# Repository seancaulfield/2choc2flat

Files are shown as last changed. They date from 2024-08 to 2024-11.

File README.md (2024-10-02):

# 2 Choc 2 Flat v1.5 and v2.1

2 Choc 2 Flat PCB
Low profile 60% PCB designed for Choc V2 switches in hot swap sockets. Based on the Plain60-C design. Four versions are provided:

* ISO(ish) without lighting
* ANSI without lighting
* ISO(ish) with RGB per-key and underglow
* ANSI with RGB per-key and underglow (TODO)

## Features

- Compatible with QMK Firmware
- Compatible with cases supporting the GH60 layout
- LED for capslock for non-RGB versions
- Minimal layout support due to hot swap sockets
- ANSI has 64 keys; ISO(ish) has 65 (split backspace)
- Both use 2U left shift keys to squeeze in the arrow cluster

## Notes/Cautions

ISO(ish) boards will need to get a custom plate cut, as there are no
commercially available ones I've found. Files for this are included in the
`plate` directory within the project directory for each ISO version.

The layout used is the 2U left shift 60% layout, which allows the arrow cluster
to be included. Check your keycap compatibility before using.

## Bill of materials (BOM)

For all versions:

* 64-65 Kailh Choc hot swap sockets (depending on variant)
* 64-65 SOD-323 diodes
* Gateron low-profile stabilizers (1 6.25U, 2-3 2U)
* Plate compatible with Gateron low-profile stabilizers
  * any Cherry plate mount stabilizer compatible should do
  * e.g. [this one at Adafruit](https://www.adafruit.com/product/5133)
  * DXF/SVG/EPS files for ISOish plates are in the project directories for them
* Waveshare RP2040 Tiny, which has the USB port attached via FFC
  * [Amazon](https://www.amazon.com/dp/B0C4FC84V9)
  * [Aliexpress](https://www.aliexpress.us/item/3256806201372671.html)

For non-RGB versions, you will also need:

* 2 1206 reverse mount LEDs (for capslock)
* 2 0603 ~470ohm resistors (for capslock LEDs)

For RGB versions, you will also need:

* 64-65 SK6812-E reverse mount NeoPixel RGB LEDs
* 16 NeoPixel Nano 2020 RGB LEDs
* 1 SN74LVC2G125DCT SSOP-8 buffer chip
* 0603 1u(ish) X5R capacitor

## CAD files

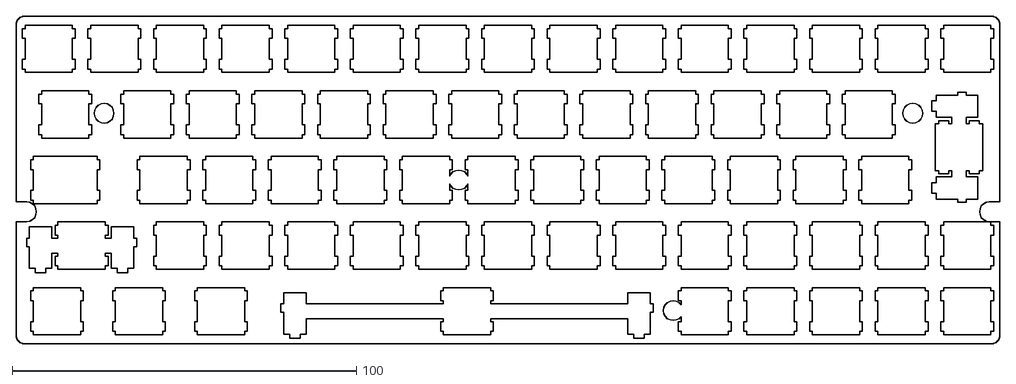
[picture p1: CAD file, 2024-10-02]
2choc2flat-extmcu-iso-solder/plate/s64-2u-lshift-iso-plate-2.dxf
285.6 x 95.2

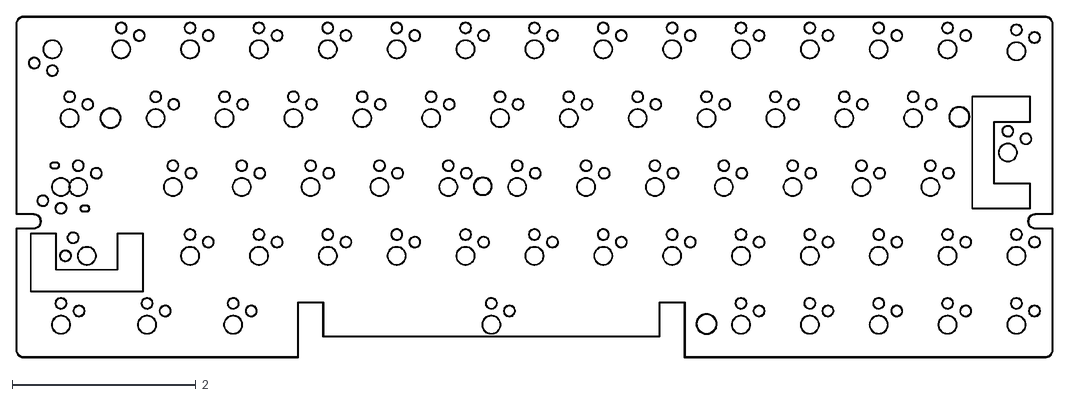
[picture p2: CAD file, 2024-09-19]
2choc2flat-extmcu-iso-solder/foam/2choc2flat-extmcu-iso-User_Eco2_v2.3.dxf
11.3 x 3.72

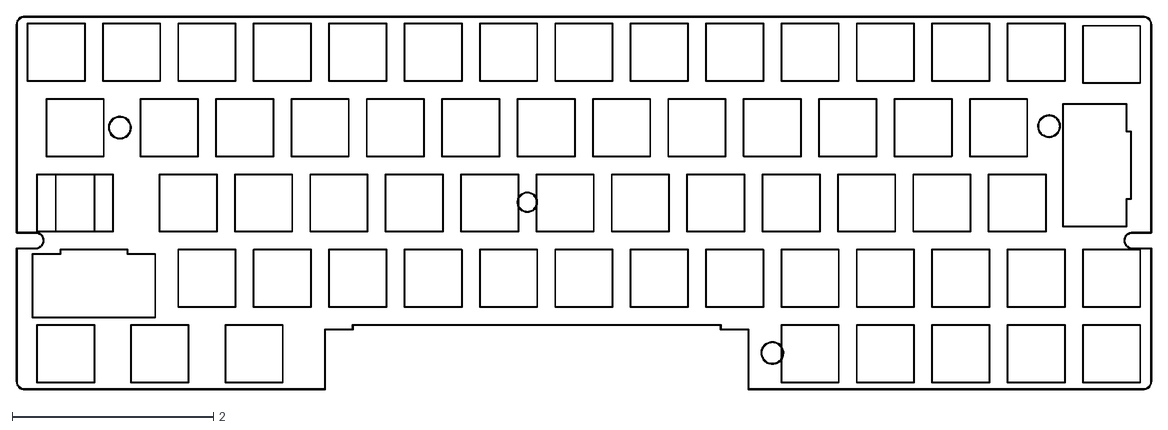
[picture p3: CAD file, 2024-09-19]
2choc2flat-extmcu-iso-solder/foam/2choc2flat-extmcu-iso-User_Eco1_v2.3.dxf
11.3 x 3.72

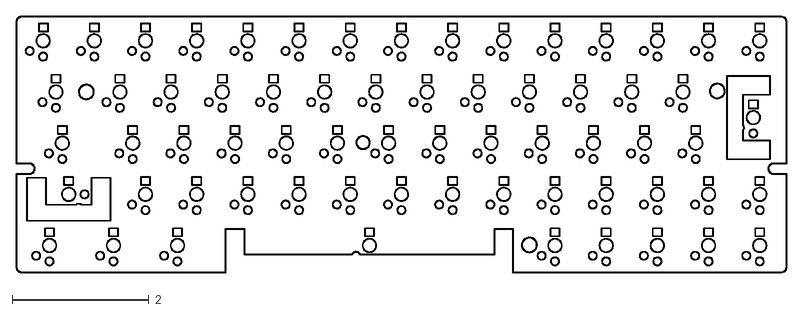
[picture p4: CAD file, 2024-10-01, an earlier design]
2choc2flat-extmcu-iso-solder/foam/2choc2flat-extmcu-iso-User_Eco2_v2.1.dxf
11.3 x 3.76

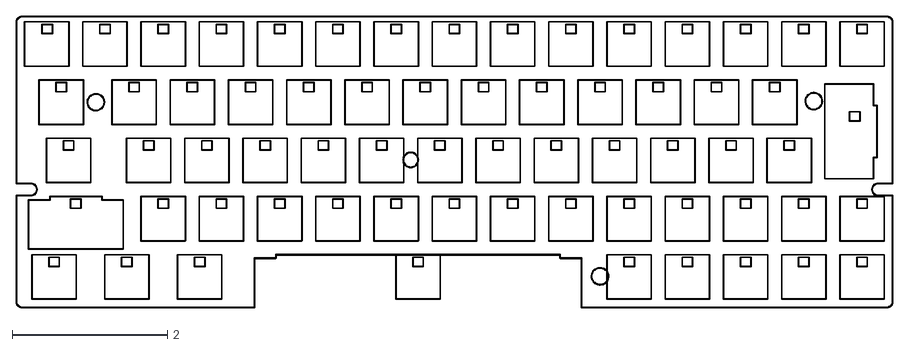
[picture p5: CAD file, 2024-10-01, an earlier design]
2choc2flat-extmcu-iso-solder/foam/2choc2flat-extmcu-iso-User_Eco1_v2.1.dxf
11.3 x 3.76

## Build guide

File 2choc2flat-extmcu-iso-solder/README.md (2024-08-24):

# Plain60-C rev2.2

Plain60-C PCB
This universal 60% PCB is designed to support as little layouts as possible without limiting usability for most users. The reason I did this is because other PCBs made for this form factor usually have so many supported layouts that it could almost qualify as swiss cheese.

It also features a fuse and an ESD protection chip to protect the MCU and other parts of the PCB.

## Features
- Compatible with QMK Firmware and VIA Configurator (if you flash a VIA compatible .hex file)
- Compatible with most universal 60% cases and HHKB/WKL Tofu by KBDfans
- USB type-C
- Optional JST header for connection with daughterboard
- Footprint for optional speaker (AST1109MLTRQ)
- ESD protection and fuse
- No LEDs and no underglow
- Minimal layout support
- ISP header

## Supported layouts
Supported layouts of the Plain60-C

## Building
If you feel like building a few of these PCBs yourself, go to the 'Releases' tab and download the latest gerber files. Order those at your favourite PCB manufacturer, get the components needed (see below) and solder them on! A hot air station is not required but a soldering iron is. Flux is recommended.

## Opening the project
To open the files you will need the latest KiCAD nightly version.

## Bill of materials (BOM)
Amount is per PCB, multiply as needed.

| LCSC part # | Description | Value | Package  | Amount |
| --- | --- | ----- | --- | ---:|
| C128353 | Capacitor | 0.1uF | 0805 | 4 |
| C131056 | Capacitor | 4.7uF | 0805 | 1 |
| C215803 | Capacitor | 1uF | 0805 | 1 |
| C109001 | Diode | | 0805 | 65 |
| C261942 | Fuse | | 0805 | 1 |
| C165948 | Connector | | SMD/THT  | 1 |
| C103904 | Resistor | 10K | 0805 | 2 |
| C212411 | Resistor | 5.1K  | 0805 | 2 |
| C325772 | Resistor | 22 | 0805 | 2 |
| C44854 | MCU | 32U4  | QFP-44 | 1 |
| C7519 | ESD chip | | SOT23-6  | 1 |
| C341521 | Resonator | 16MHz | SMD | 1 |
| C92584 | Switch | | SMD | 1 |
| C160404 | Optional JST  | | SMD | 1 |

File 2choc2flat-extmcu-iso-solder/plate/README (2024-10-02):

The files in this directory were created with this plate builder site:

http://builder.swillkb.com/

The keyboard layout JSON file is also included. Plates were generated with 0.25mm kerf.

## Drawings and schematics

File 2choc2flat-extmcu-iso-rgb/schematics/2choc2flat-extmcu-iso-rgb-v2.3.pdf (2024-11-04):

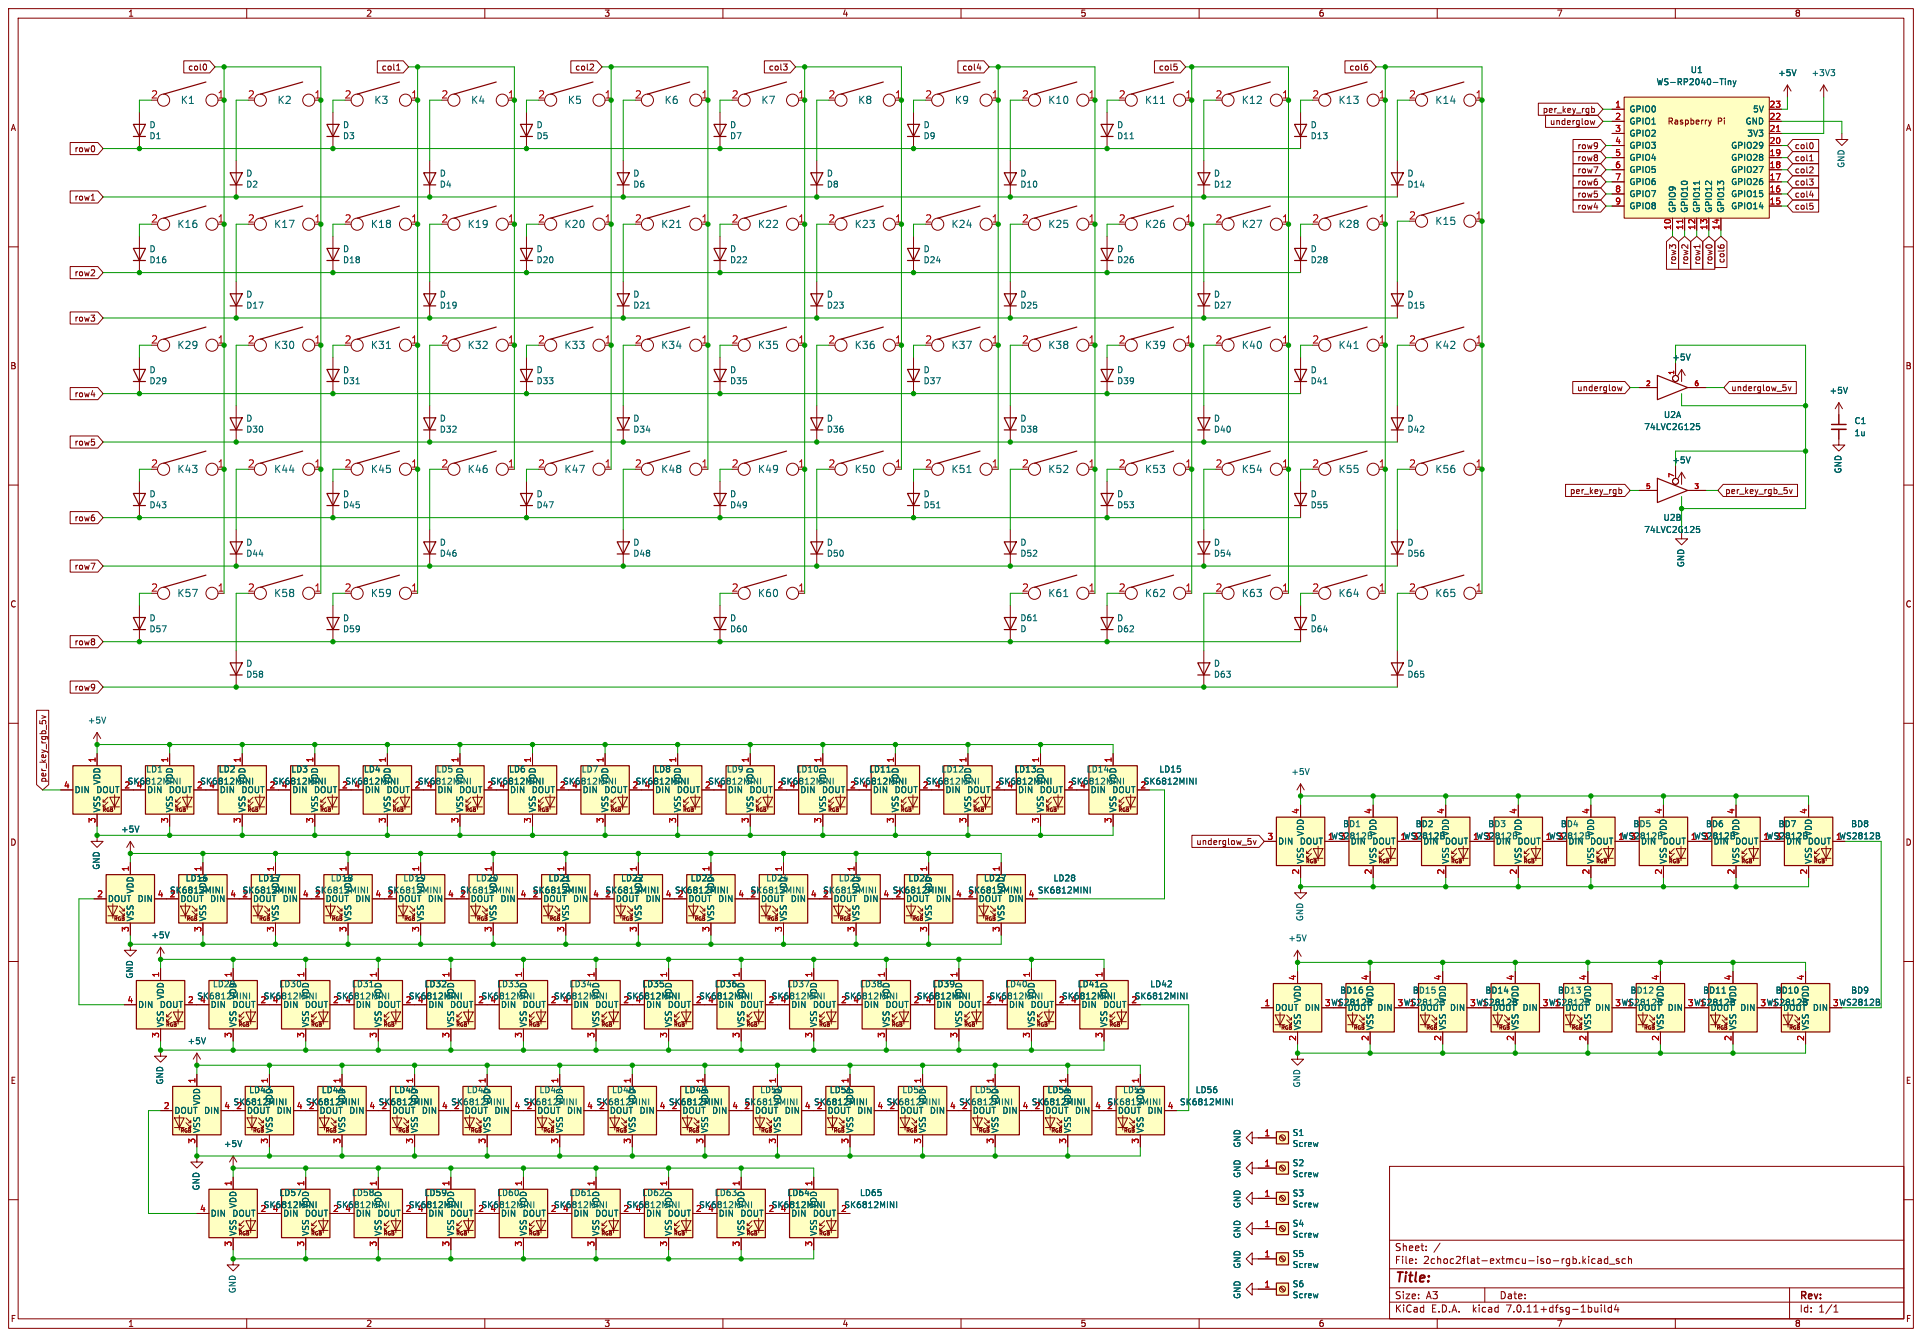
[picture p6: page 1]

Id: 1/1 Title: File: 2choc2flat-extmcu-iso-rgb.kicad_sch Sheet: /

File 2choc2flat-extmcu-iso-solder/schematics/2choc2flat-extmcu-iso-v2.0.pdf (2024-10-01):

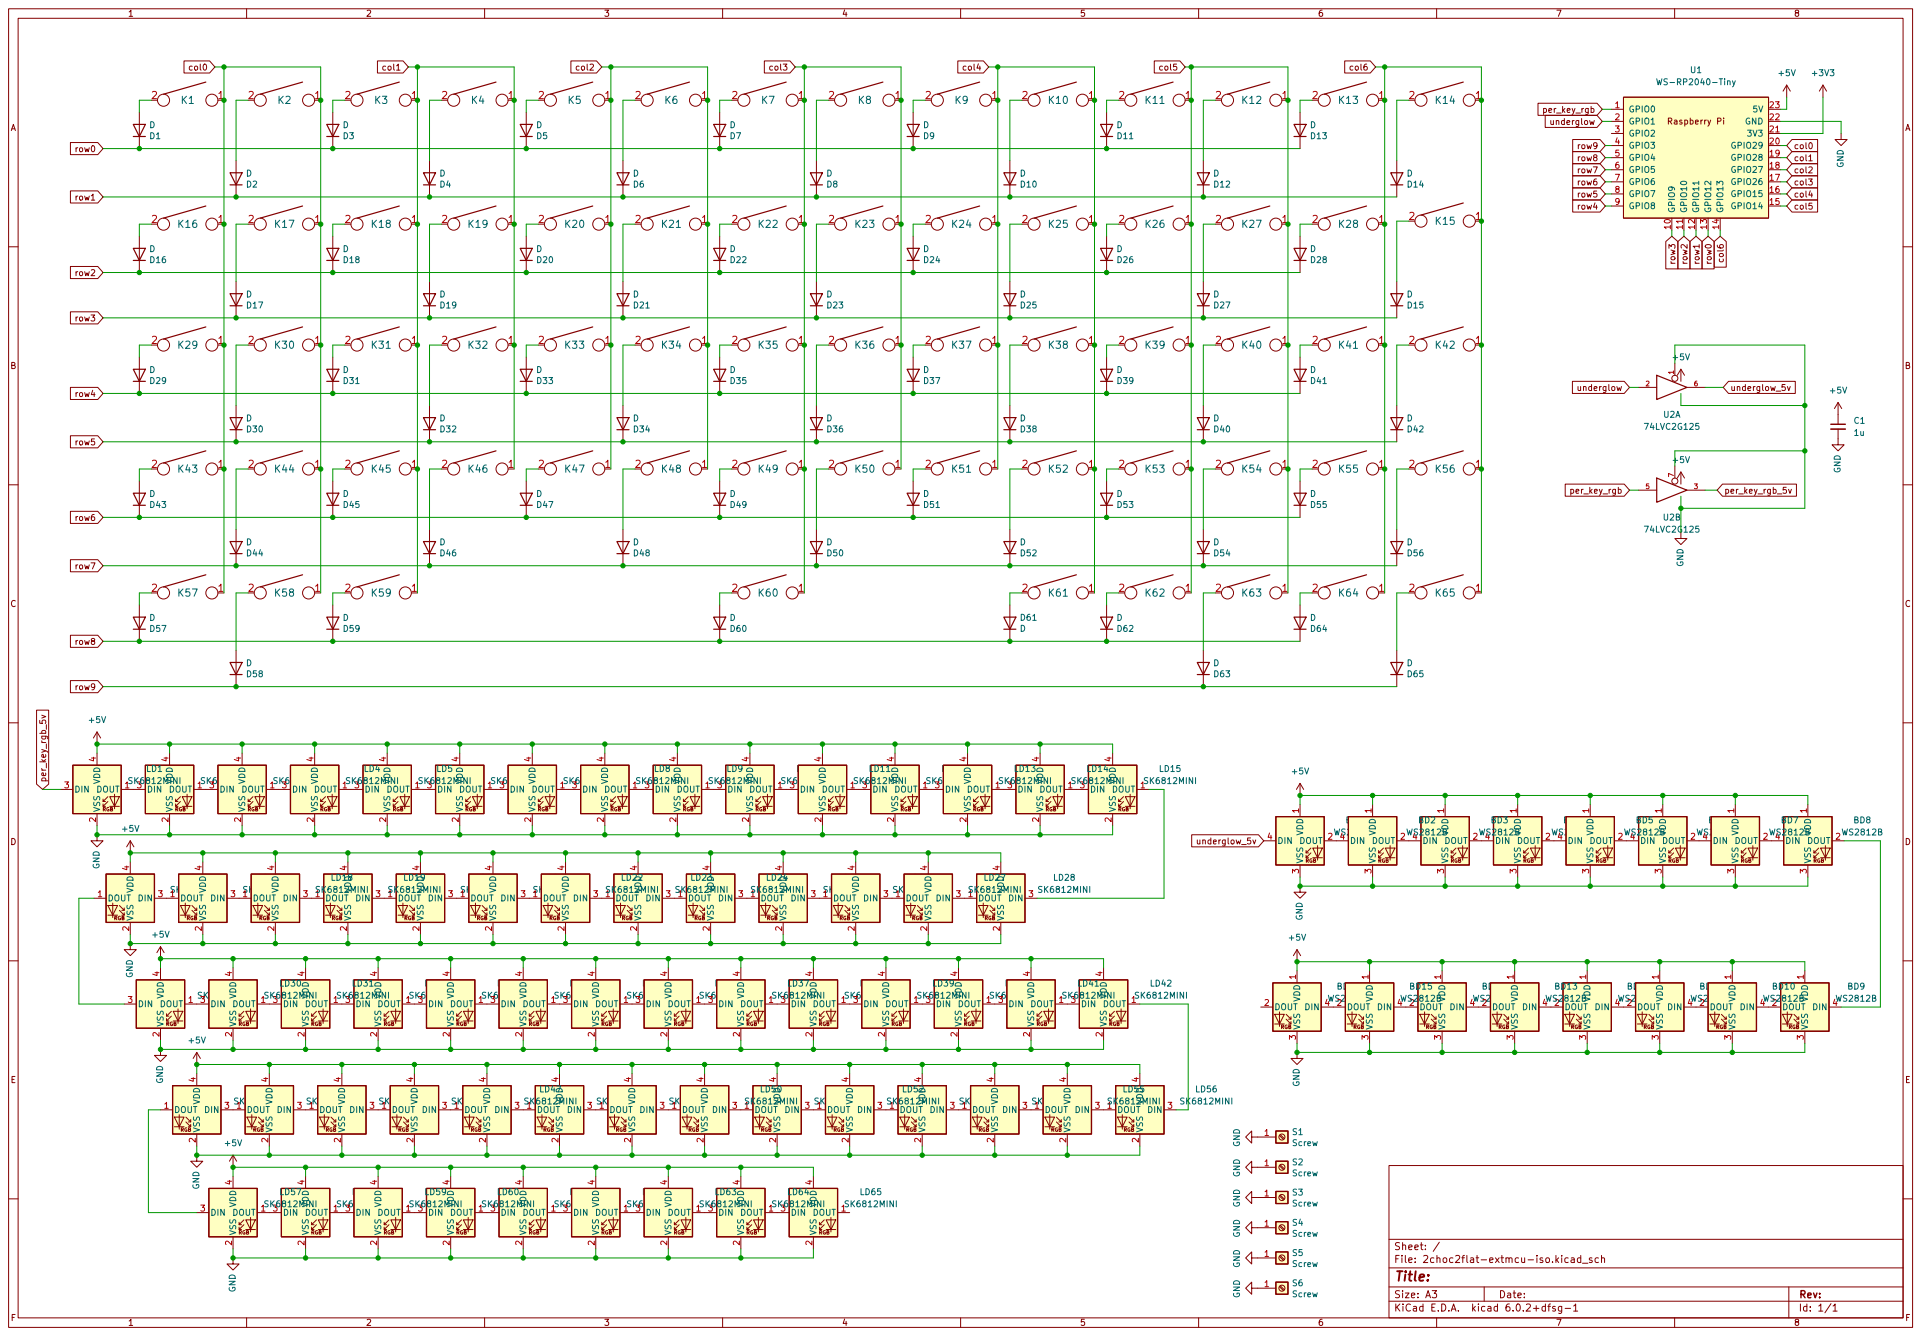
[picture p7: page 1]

File: 2choc2flat-extmcu-iso.kicad_sch Sheet: / GND

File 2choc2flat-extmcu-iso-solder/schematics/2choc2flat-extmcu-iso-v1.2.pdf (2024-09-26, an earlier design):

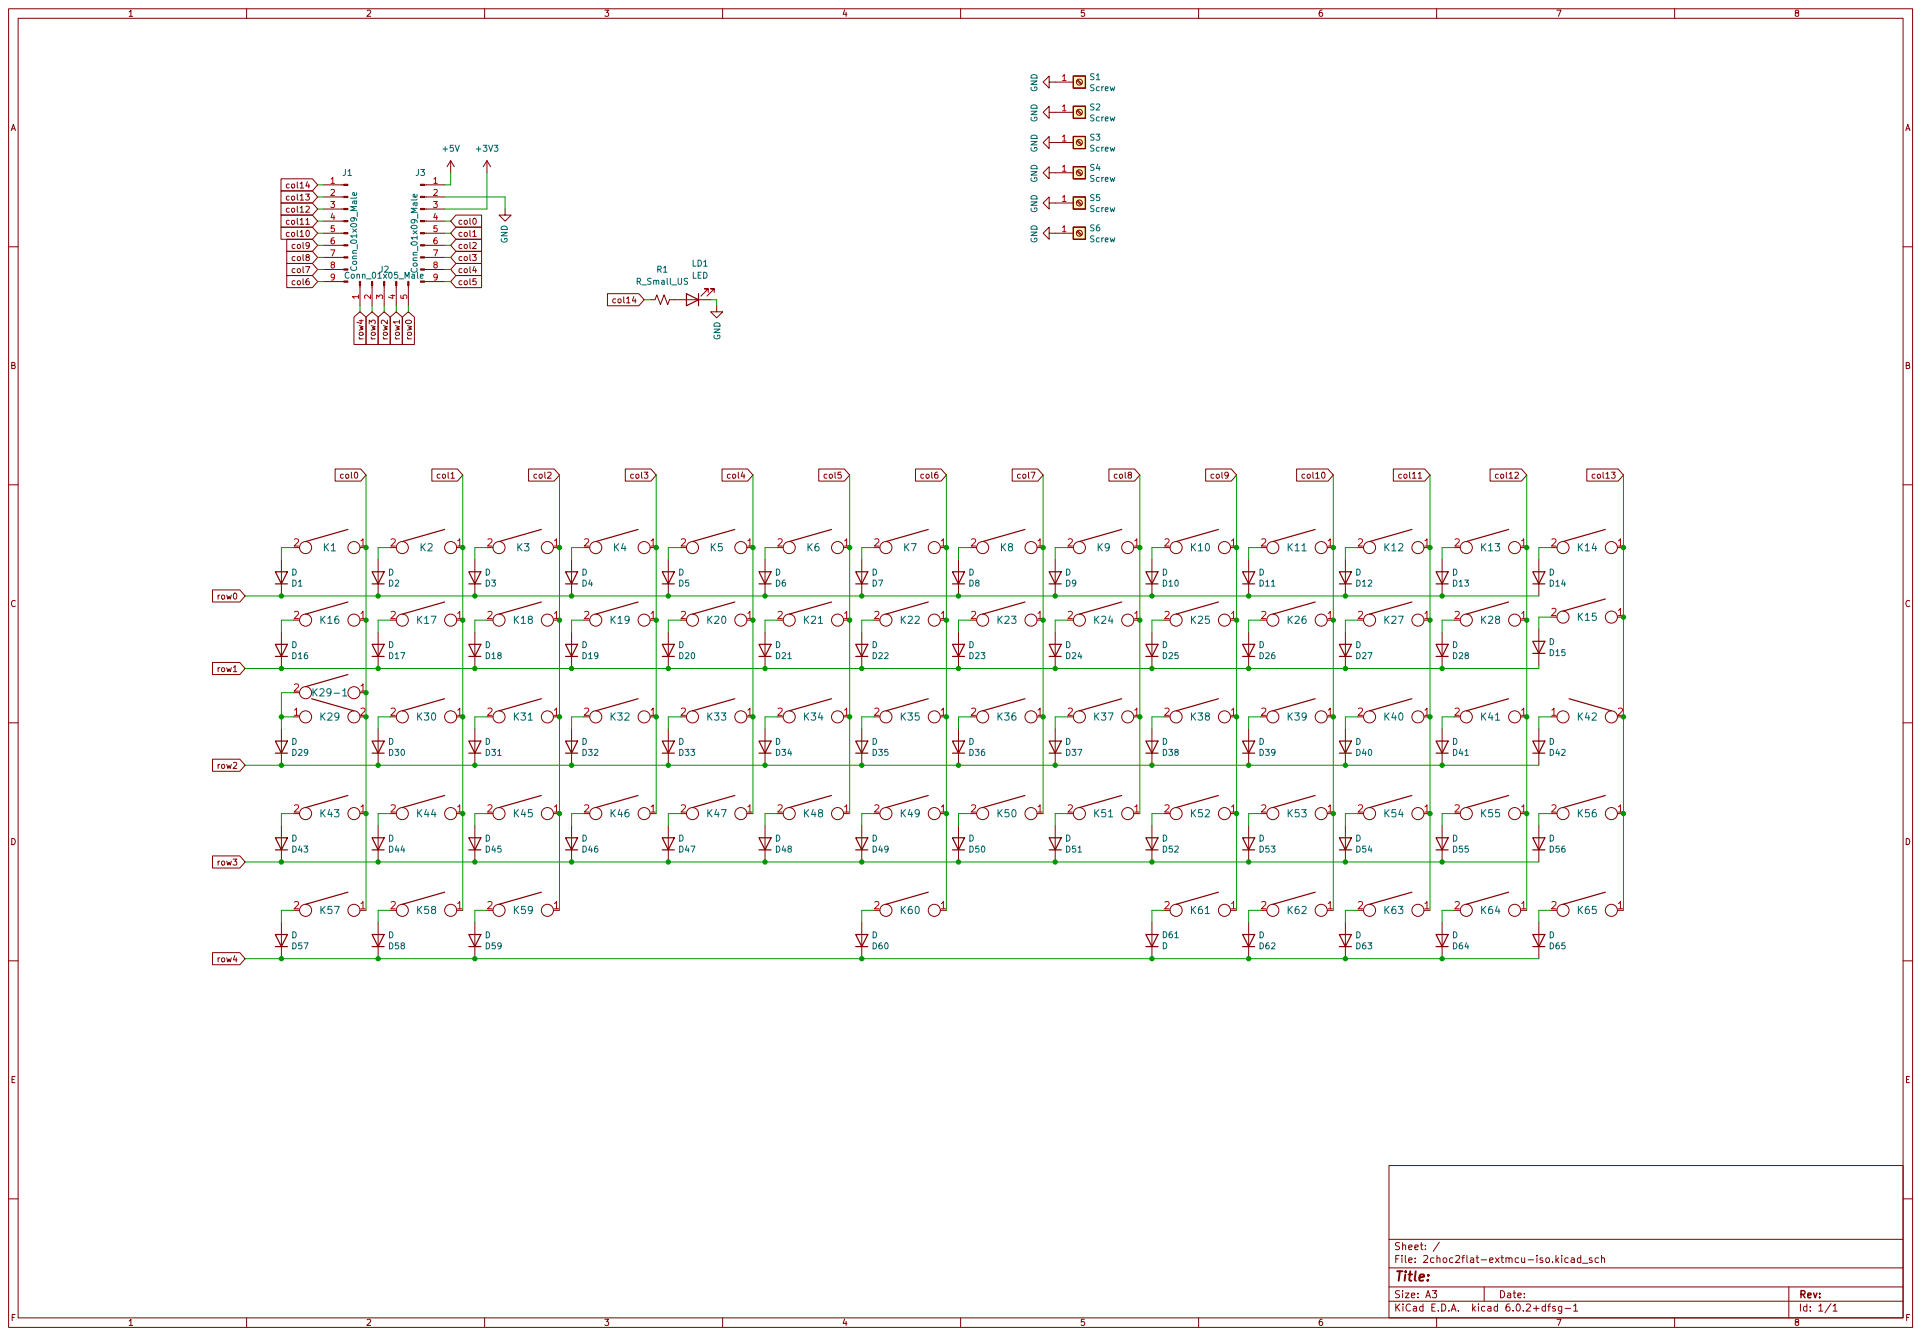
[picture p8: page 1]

File: 2choc2flat-extmcu-iso.kicad_sch Sheet: /

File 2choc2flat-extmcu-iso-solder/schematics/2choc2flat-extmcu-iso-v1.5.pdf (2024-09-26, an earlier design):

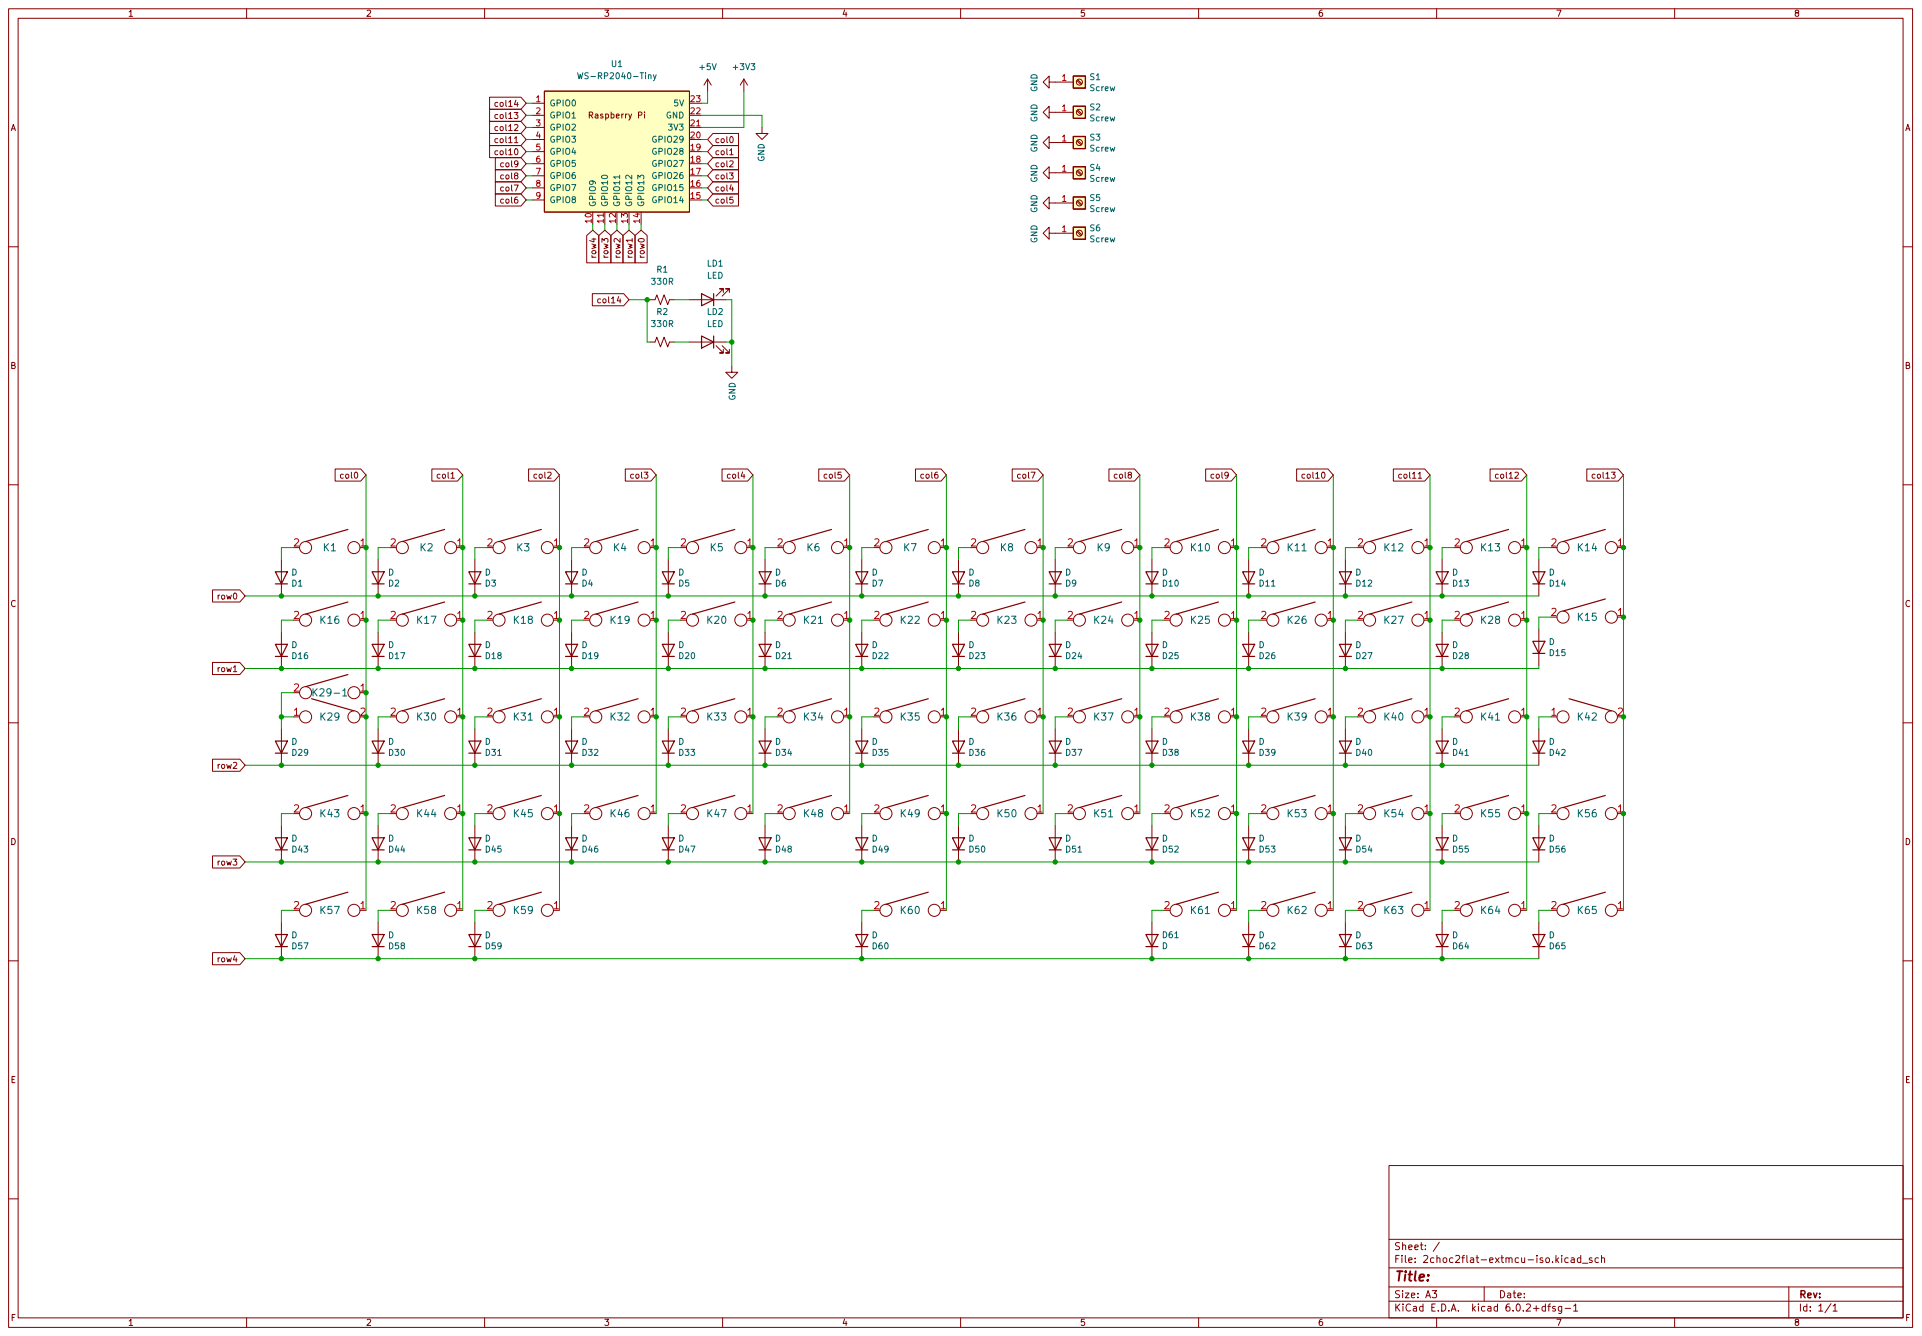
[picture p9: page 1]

File: 2choc2flat-extmcu-iso.kicad_sch Sheet: /

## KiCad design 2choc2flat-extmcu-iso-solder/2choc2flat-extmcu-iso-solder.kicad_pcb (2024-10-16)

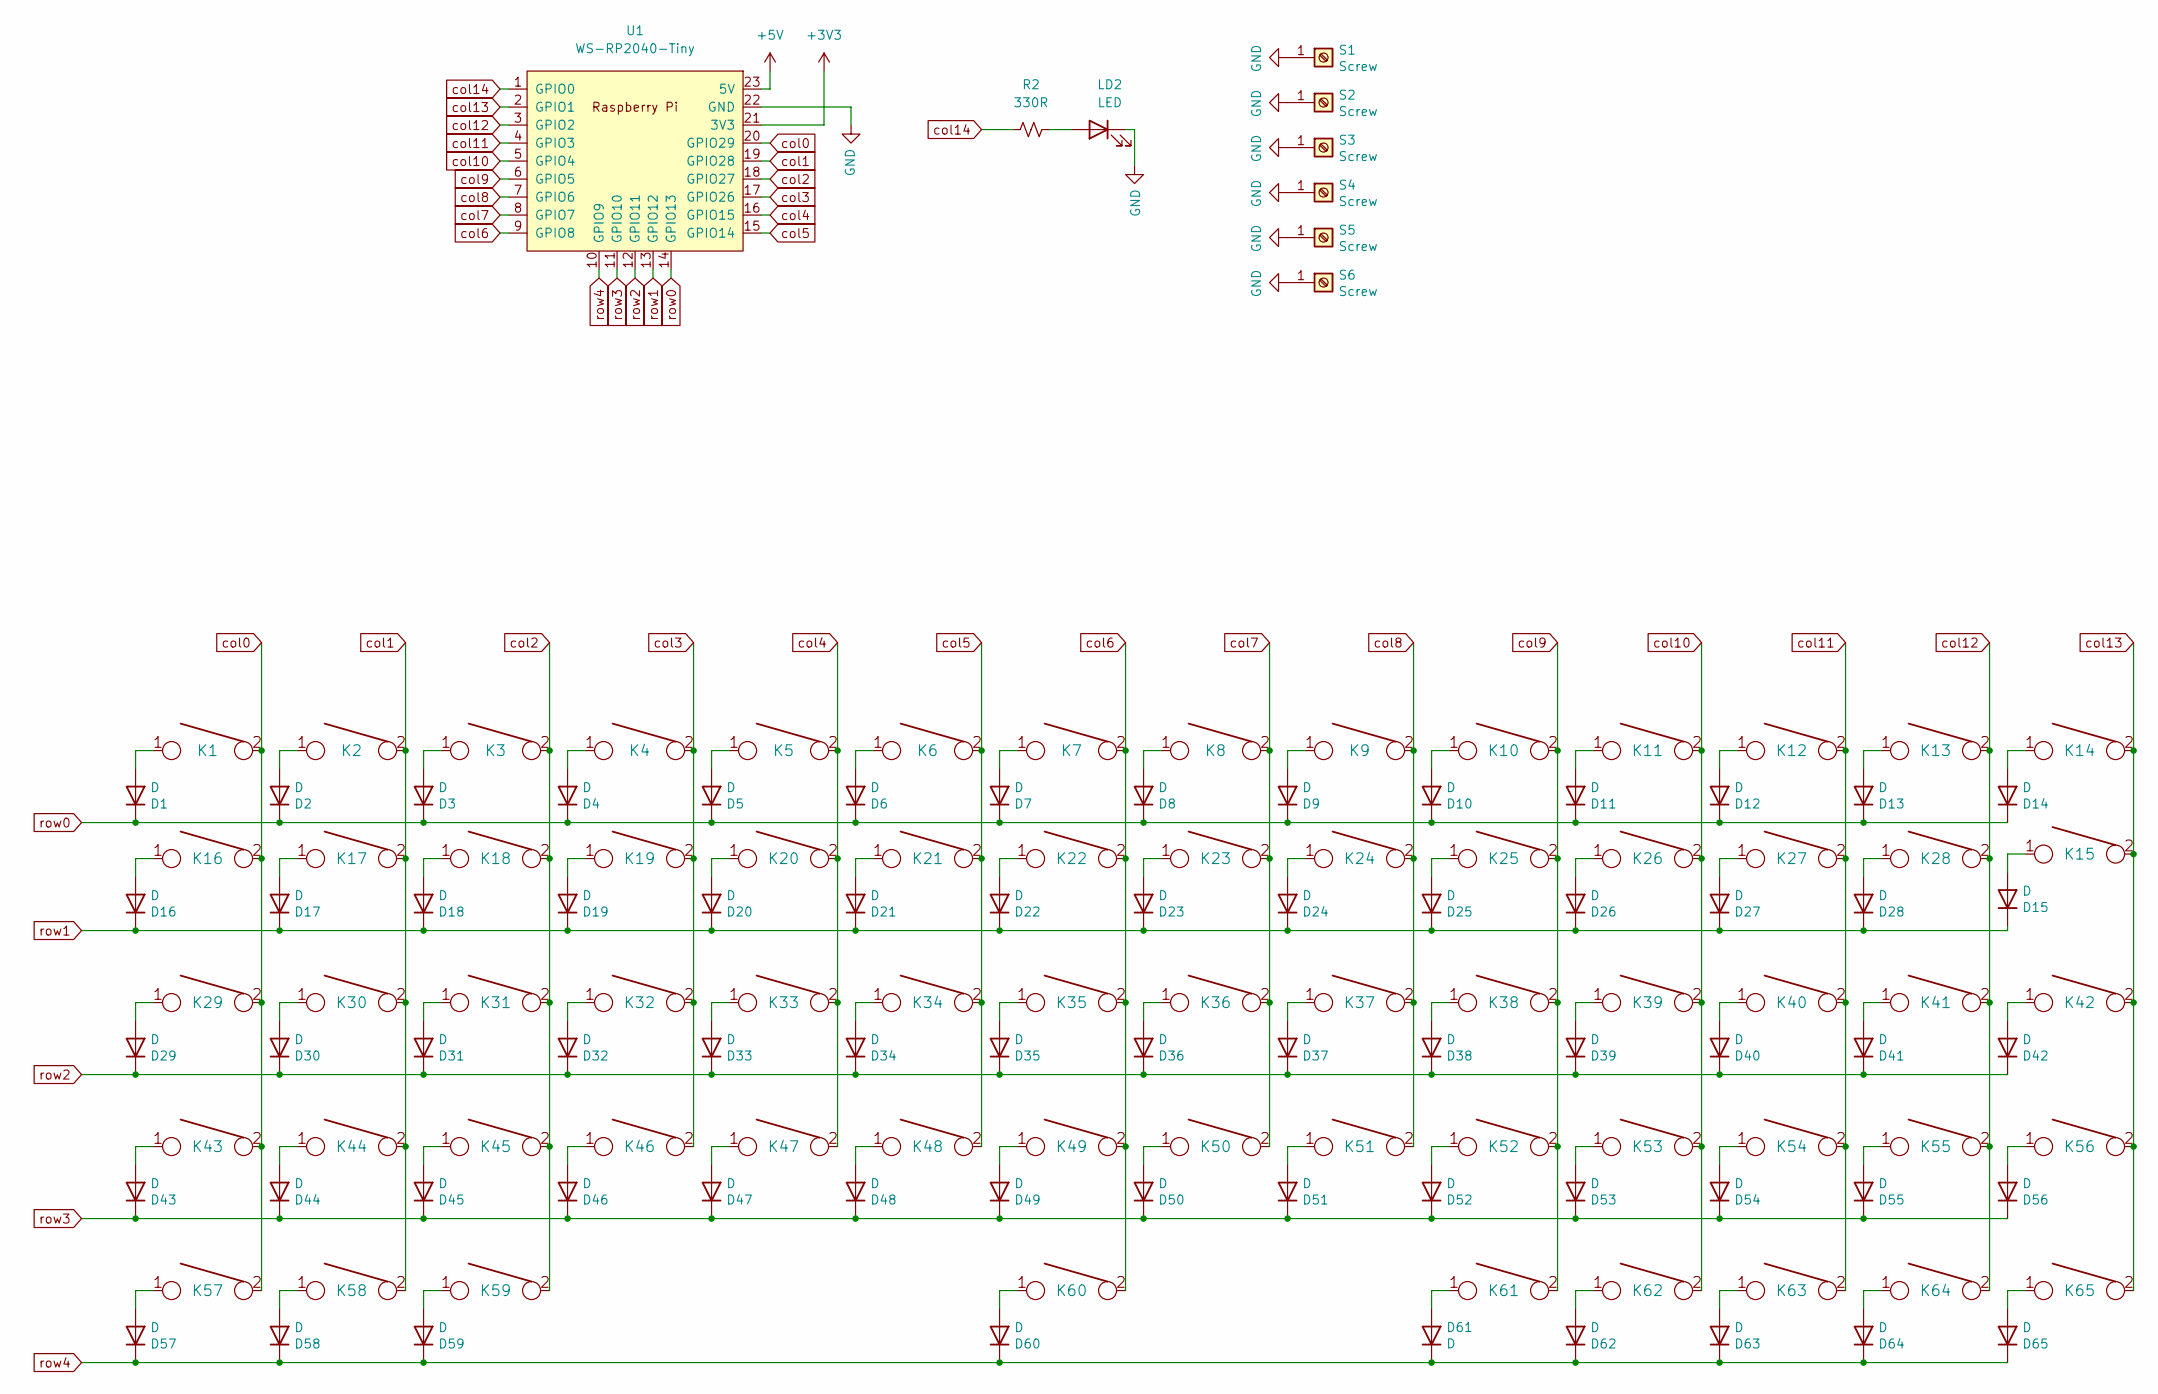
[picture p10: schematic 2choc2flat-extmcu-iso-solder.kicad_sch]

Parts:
D1, D2, D3, D4, D5, D6, D7, D8, D9, D10, D11, D12, D13, D14, D15, D16, D17, D18, D19, D20, D21, D22, D23, D24, D25, D26, D27, D28, D29, D30, D31, D32, D33, D34, D35, D36, D37, D38, D39, D40, D41, D42, D43, D44, D45, D46, D47, D48, D49, D50, D51, D52, D53, D54, D55, D56, D57, D58, D59, D60, D61, D62, D63, D64, D65: D; D_SOD-323_HandSoldering
K1, K2, K3, K4, K5, K6, K7, K8, K9, K10, K11, K12, K13, K14, K15, K17, K18, K19, K20, K21, K22, K23, K24, K25, K26, K27, K28, K30, K31, K32, K33, K34, K35, K36, K37, K38, K39, K40, K41, K44, K45, K46, K47, K48, K49, K50, K51, K52, K53, K54, K55, K56, K61, K62, K63, K64, K65: KEYSW; SW_Soldered_Kailh_Choc_V2_1.00u
K16: KEYSW; SW_Soldered_Kailh_Choc_V2_1.50u
K29: KEYSW; SW_Soldered_Kailh_Choc_V2_1.75u
K42: KEYSW; SW_Soldered_Kailh_Choc_V2_ISOEnter_West_Gateron_LP_Stabs
K43: KEYSW; SW_Soldered_Kailh_Choc_V2_2.00u_0deg_Gateron_LP_Stabs
K57, K58, K59: KEYSW; SW_Soldered_Kailh_Choc_V2_1.25u
K60: KEYSW; SW_Soldered_Kailh_Choc_V2_6.25u
LD2: LED; LED_1206_3216Metric_ReverseMount_Hole1.8x2.4mm
R2: 330R; R_0603_1608Metric
S1, S2, S6: Screw; 3_5x2.5mm
S3: Screw; MountingHole_2.2mm_M2_Pad_TopOnly
S4, S5: Screw; 8x3.5_7x2.5mm
U1: WS-RP2040-Tiny; WAVESHARE_RP2040_TINY_SLIM

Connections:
+3V3: U1.21 (3V3)
+5V: U1.23 (5V)
GND: LD2.1 (K), S1.1, S2.1, S3.1, S4.1, S5.1, S6.1, U1.22 (GND)
unnamed: D1.2 (A), K1.1
unnamed: D2.2 (A), K2.1
unnamed: D3.2 (A), K3.1
unnamed: D4.2 (A), K4.1
unnamed: D5.2 (A), K5.1
unnamed: D6.2 (A), K6.1
unnamed: D7.2 (A), K7.1
unnamed: D8.2 (A), K8.1
unnamed: D9.2 (A), K9.1
unnamed: D10.2 (A), K10.1
unnamed: D11.2 (A), K11.1
unnamed: D12.2 (A), K12.1
unnamed: D13.2 (A), K13.1
unnamed: D14.2 (A), K14.1
unnamed: D15.2 (A), K15.1
unnamed: D16.2 (A), K16.1
unnamed: D17.2 (A), K17.1
unnamed: D18.2 (A), K18.1
unnamed: D19.2 (A), K19.1
unnamed: D20.2 (A), K20.1
unnamed: D21.2 (A), K21.1
unnamed: D22.2 (A), K22.1
unnamed: D23.2 (A), K23.1
unnamed: D24.2 (A), K24.1
unnamed: D25.2 (A), K25.1
unnamed: D26.2 (A), K26.1
unnamed: D27.2 (A), K27.1
unnamed: D28.2 (A), K28.1
unnamed: D29.2 (A), K29.1
unnamed: D30.2 (A), K30.1
unnamed: D31.2 (A), K31.1
unnamed: D32.2 (A), K32.1
unnamed: D33.2 (A), K33.1
unnamed: D34.2 (A), K34.1
unnamed: D35.2 (A), K35.1
unnamed: D36.2 (A), K36.1
unnamed: D37.2 (A), K37.1
unnamed: D38.2 (A), K38.1
unnamed: D39.2 (A), K39.1
unnamed: D40.2 (A), K40.1
unnamed: D41.2 (A), K41.1
unnamed: D42.2 (A), K42.1
unnamed: D43.2 (A), K43.1
unnamed: D44.2 (A), K44.1
unnamed: D45.2 (A), K45.1
unnamed: D46.2 (A), K46.1
unnamed: D47.2 (A), K47.1
unnamed: D48.2 (A), K48.1
unnamed: D49.2 (A), K49.1
unnamed: D50.2 (A), K50.1
unnamed: D51.2 (A), K51.1
unnamed: D52.2 (A), K52.1
unnamed: D53.2 (A), K53.1
unnamed: D54.2 (A), K54.1
unnamed: D55.2 (A), K55.1
unnamed: D56.2 (A), K56.1
unnamed: D57.2 (A), K57.1
unnamed: D58.2 (A), K58.1
unnamed: D59.2 (A), K59.1
unnamed: D60.2 (A), K60.1
unnamed: D61.2 (A), K61.1
unnamed: D62.2 (A), K62.1
unnamed: D63.2 (A), K63.1
unnamed: D64.2 (A), K64.1
unnamed: D65.2 (A), K65.1
unnamed: LD2.2 (A), R2.2
col0: K1.2, K16.2, K29.2, K43.2, K57.2, U1.20 (GPIO29)
col1: K2.2, K17.2, K30.2, K44.2, K58.2, U1.19 (GPIO28)
col2: K3.2, K18.2, K31.2, K45.2, K59.2, U1.18 (GPIO27)
col3: K4.2, K19.2, K32.2, K46.2, U1.17 (GPIO26)
col4: K5.2, K20.2, K33.2, K47.2, U1.16 (GPIO15)
col5: K6.2, K21.2, K34.2, K48.2, U1.15 (GPIO14)
col6: K7.2, K22.2, K35.2, K49.2, K60.2, U1.9 (GPIO8)
col7: K8.2, K23.2, K36.2, K50.2, U1.8 (GPIO7)
col8: K9.2, K24.2, K37.2, K51.2, U1.7 (GPIO6)
col9: K10.2, K25.2, K38.2, K52.2, K61.2, U1.6 (GPIO5)
col10: K11.2, K26.2, K39.2, K53.2, K62.2, U1.5 (GPIO4)
col11: K12.2, K27.2, K40.2, K54.2, K63.2, U1.4 (GPIO3)
col12: K13.2, K28.2, K41.2, K55.2, K64.2, U1.3 (GPIO2)
col13: K14.2, K15.2, K42.2, K56.2, K65.2, U1.2 (GPIO1)
col14: R2.1, U1.1 (GPIO0)
row0: D1.1 (K), D2.1 (K), D3.1 (K), D4.1 (K), D5.1 (K), D6.1 (K), D7.1 (K), D8.1 (K), D9.1 (K), D10.1 (K), D11.1 (K), D12.1 (K), D13.1 (K), D14.1 (K), U1.14 (GPIO13)
row1: D15.1 (K), D16.1 (K), D17.1 (K), D18.1 (K), D19.1 (K), D20.1 (K), D21.1 (K), D22.1 (K), D23.1 (K), D24.1 (K), D25.1 (K), D26.1 (K), D27.1 (K), D28.1 (K), U1.13 (GPIO12)
row2: D29.1 (K), D30.1 (K), D31.1 (K), D32.1 (K), D33.1 (K), D34.1 (K), D35.1 (K), D36.1 (K), D37.1 (K), D38.1 (K), D39.1 (K), D40.1 (K), D41.1 (K), D42.1 (K), U1.12 (GPIO11)
row3: D43.1 (K), D44.1 (K), D45.1 (K), D46.1 (K), D47.1 (K), D48.1 (K), D49.1 (K), D50.1 (K), D51.1 (K), D52.1 (K), D53.1 (K), D54.1 (K), D55.1 (K), D56.1 (K), U1.11 (GPIO10)
row4: D57.1 (K), D58.1 (K), D59.1 (K), D60.1 (K), D61.1 (K), D62.1 (K), D63.1 (K), D64.1 (K), D65.1 (K), U1.10 (GPIO9)

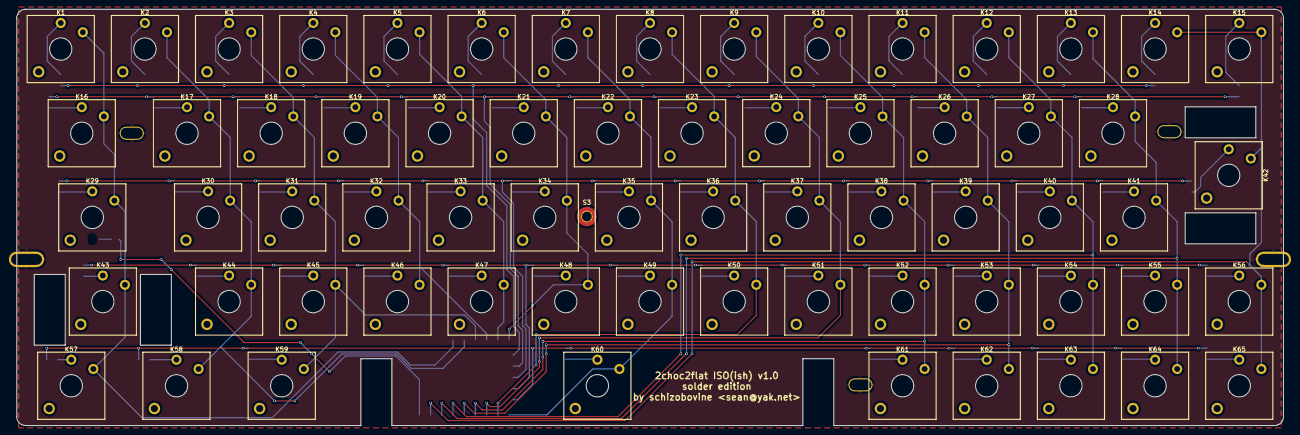
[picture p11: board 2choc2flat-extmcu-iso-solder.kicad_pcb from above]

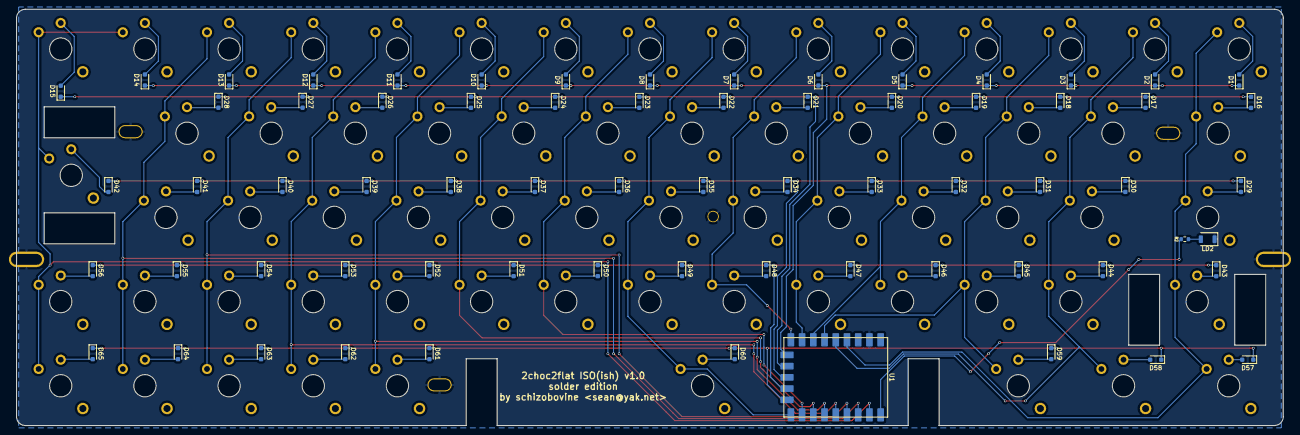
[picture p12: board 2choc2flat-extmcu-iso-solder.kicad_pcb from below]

Board: 2 copper layers, 286.7 x 94.2 mm, 139 parts (68 on the bottom side), 87 nets.

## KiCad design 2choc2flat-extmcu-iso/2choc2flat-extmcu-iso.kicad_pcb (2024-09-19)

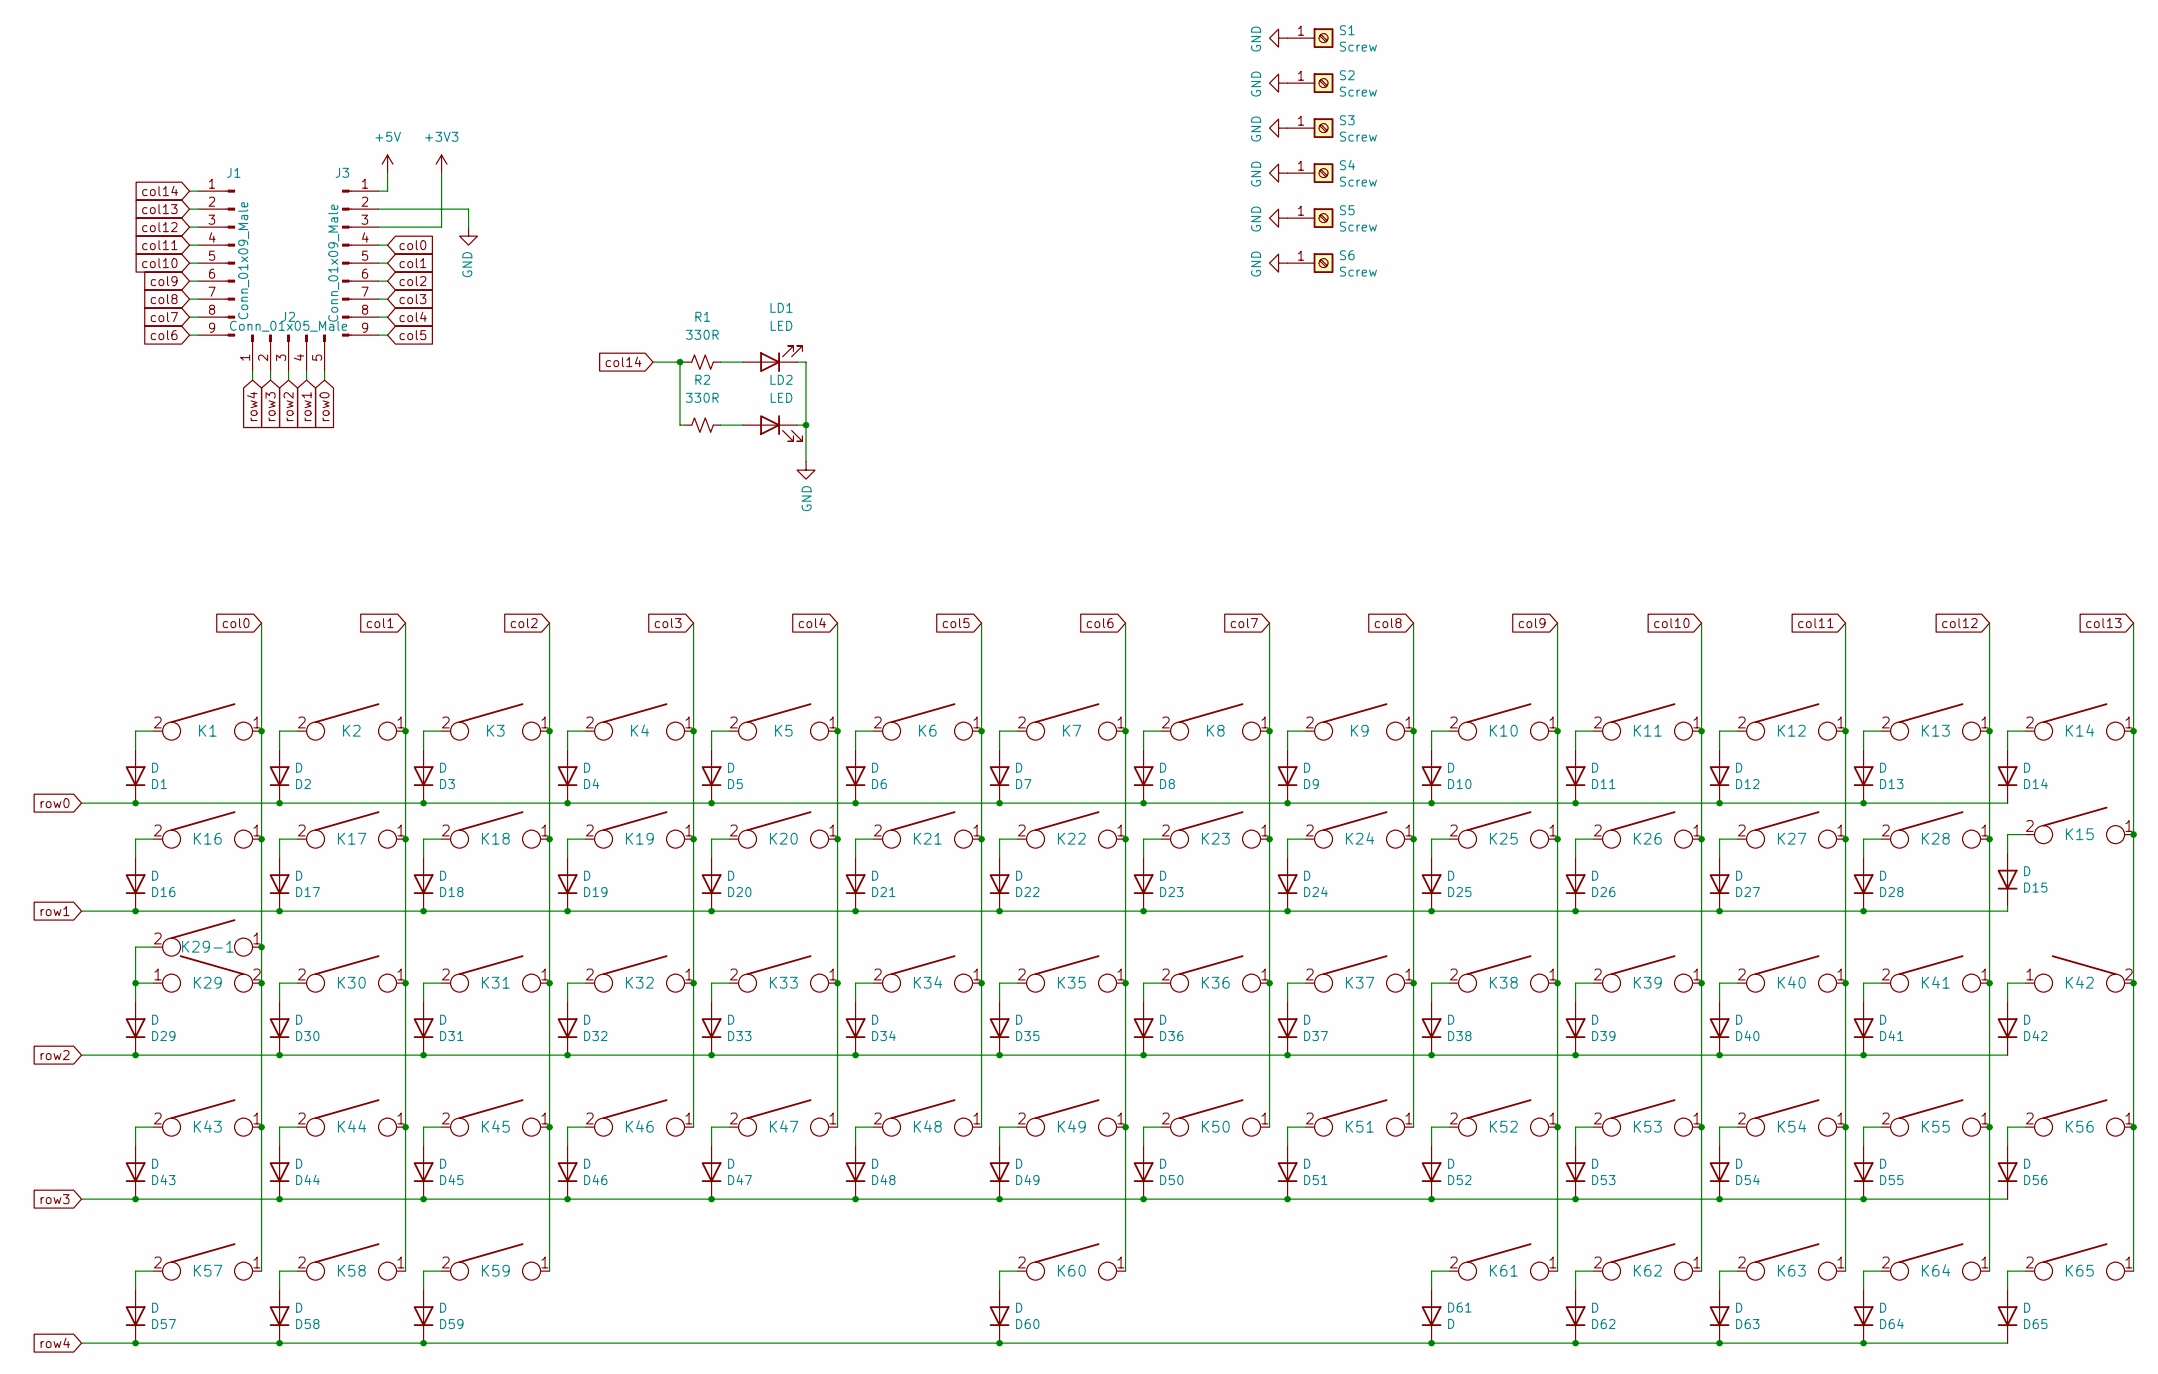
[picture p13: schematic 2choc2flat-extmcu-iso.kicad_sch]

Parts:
D1, D2, D3, D4, D5, D6, D7, D8, D9, D10, D11, D12, D13, D14, D15, D16, D17, D18, D19, D20, D21, D22, D23, D24, D25, D26, D27, D28, D29, D30, D31, D32, D33, D34, D35, D36, D37, D38, D39, D40, D41, D42, D43, D44, D45, D46, D47, D48, D49, D50, D51, D52, D53, D54, D55, D56, D57, D58, D59, D60, D61, D62, D63, D64, D65: D; D_SOD-323_HandSoldering
J1, J3: Conn_01x09_Male; PinHeader_1x09_P2.54mm_Vertical
J2: Conn_01x05_Male; PinHeader_1x05_P2.54mm_Vertical
K1, K2, K3, K4, K5, K6, K7, K8, K9, K10, K11, K12, K13, K14, K15, K17, K18, K19, K20, K21, K22, K23, K24, K25, K26, K27, K28, K30, K31, K32, K33, K34, K35, K36, K37, K38, K39, K40, K41, K44, K45, K46, K47, K48, K49, K50, K51, K52, K53, K54, K55, K56, K61, K62, K63, K64, K65: KEYSW; SW_Hotswap_Kailh_Choc_V2_1.00u
K16: KEYSW; SW_Hotswap_Kailh_Choc_V2_1.50u
K29: KEYSW; SW_Hotswap_Kailh_Choc_V2_1.75u
K29-1, K57, K58, K59: KEYSW; SW_Hotswap_Kailh_Choc_V2_1.25u
K42: KEYSW; SW_Hotswap_Kailh_Choc_V2_ISOEnter_West_Gateron_LP_Stabs
K43: KEYSW; SW_Hotswap_Kailh_Choc_V2_2.00u_90deg_Gateron_LP_Stabs
K60: KEYSW; SW_Hotswap_Kailh_Choc_V2_6.25u
LD1, LD2: LED; LED_1206_3216Metric_ReverseMount_Hole1.8x2.4mm
R1, R2: 330R; R_0603_1608Metric
S1, S2, S6: Screw; 3_5x2.5mm
S3: Screw; MountingHole_2.2mm_M2_Pad_TopOnly
S4, S5: Screw; 8x3.5_7x2.5mm

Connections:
GND: J3.2, LD1.1 (K), LD2.1 (K), S1.1, S2.1, S3.1, S4.1, S5.1, S6.1; also elsewhere on the board
unnamed: D1.2 (A), K1.2
unnamed: D2.2 (A), K2.2
unnamed: D3.2 (A), K3.2
unnamed: D4.2 (A), K4.2
unnamed: D5.2 (A), K5.2
unnamed: D6.2 (A), K6.2
unnamed: D7.2 (A), K7.2
unnamed: D8.2 (A), K8.2
unnamed: D9.2 (A), K9.2
unnamed: D10.2 (A), K10.2
unnamed: D11.2 (A), K11.2
unnamed: D12.2 (A), K12.2
unnamed: D13.2 (A), K13.2
unnamed: D14.2 (A), K14.2
unnamed: D15.2 (A), K15.2
unnamed: D16.2 (A), K16.2
unnamed: D17.2 (A), K17.2
unnamed: D18.2 (A), K18.2
unnamed: D19.2 (A), K19.2
unnamed: D20.2 (A), K20.2
unnamed: D21.2 (A), K21.2
unnamed: D22.2 (A), K22.2
unnamed: D23.2 (A), K23.2
unnamed: D24.2 (A), K24.2
unnamed: D25.2 (A), K25.2
unnamed: D26.2 (A), K26.2
unnamed: D27.2 (A), K27.2
unnamed: D28.2 (A), K28.2
unnamed: D29.2 (A), K29.1, K29-1.2
unnamed: D30.2 (A), K30.2
unnamed: D31.2 (A), K31.2
unnamed: D32.2 (A), K32.2
unnamed: D33.2 (A), K33.2
unnamed: D34.2 (A), K34.2
unnamed: D35.2 (A), K35.2
unnamed: D36.2 (A), K36.2
unnamed: D37.2 (A), K37.2
unnamed: D38.2 (A), K38.2
unnamed: D39.2 (A), K39.2
unnamed: D40.2 (A), K40.2
unnamed: D41.2 (A), K41.2
unnamed: D42.2 (A), K42.1
unnamed: D43.2 (A), K43.2
unnamed: D44.2 (A), K44.2
unnamed: D45.2 (A), K45.2
unnamed: D46.2 (A), K46.2
unnamed: D47.2 (A), K47.2
unnamed: D48.2 (A), K48.2
unnamed: D49.2 (A), K49.2
unnamed: D50.2 (A), K50.2
unnamed: D51.2 (A), K51.2
unnamed: D52.2 (A), K52.2
unnamed: D53.2 (A), K53.2
unnamed: D54.2 (A), K54.2
unnamed: D55.2 (A), K55.2
unnamed: D56.2 (A), K56.2
unnamed: D57.2 (A), K57.2
unnamed: D58.2 (A), K58.2
unnamed: D59.2 (A), K59.2
unnamed: D60.2 (A), K60.2
unnamed: D61.2 (A), K61.2
unnamed: D62.2 (A), K62.2
unnamed: D63.2 (A), K63.2
unnamed: D64.2 (A), K64.2
unnamed: D65.2 (A), K65.2
unnamed: LD1.2 (A), R1.2
unnamed: LD2.2 (A), R2.2
col0: J3.4, K1.1, K16.1, K29.2, K29-1.1, K43.1, K57.1; also elsewhere on the board
col1: J3.5, K2.1, K17.1, K30.1, K44.1, K58.1; also elsewhere on the board
col2: J3.6, K3.1, K18.1, K31.1, K45.1, K59.1; also elsewhere on the board
col3: J3.7, K4.1, K19.1, K32.1, K46.1; also elsewhere on the board
col4: J3.8, K5.1, K20.1, K33.1, K47.1; also elsewhere on the board
col5: J3.9, K6.1, K21.1, K34.1, K48.1; also elsewhere on the board
col6: J1.9, K7.1, K22.1, K35.1, K49.1, K60.1; also elsewhere on the board
col7: J1.8, K8.1, K23.1, K36.1, K50.1; also elsewhere on the board
col8: J1.7, K9.1, K24.1, K37.1, K51.1; also elsewhere on the board
col9: J1.6, K10.1, K25.1, K38.1, K52.1, K61.1; also elsewhere on the board
col10: J1.5, K11.1, K26.1, K39.1, K53.1, K62.1; also elsewhere on the board
col11: J1.4, K12.1, K27.1, K40.1, K54.1, K63.1; also elsewhere on the board
col12: J1.3, K13.1, K28.1, K41.1, K55.1, K64.1; also elsewhere on the board
col13: J1.2, K14.1, K15.1, K42.2, K56.1, K65.1; also elsewhere on the board
col14: J1.1, R1.1, R2.1; also elsewhere on the board
row0: D1.1 (K), D2.1 (K), D3.1 (K), D4.1 (K), D5.1 (K), D6.1 (K), D7.1 (K), D8.1 (K), D9.1 (K), D10.1 (K), D11.1 (K), D12.1 (K), D13.1 (K), D14.1 (K), J2.5; also elsewhere on the board
row1: D15.1 (K), D16.1 (K), D17.1 (K), D18.1 (K), D19.1 (K), D20.1 (K), D21.1 (K), D22.1 (K), D23.1 (K), D24.1 (K), D25.1 (K), D26.1 (K), D27.1 (K), D28.1 (K), J2.4; also elsewhere on the board
row2: D29.1 (K), D30.1 (K), D31.1 (K), D32.1 (K), D33.1 (K), D34.1 (K), D35.1 (K), D36.1 (K), D37.1 (K), D38.1 (K), D39.1 (K), D40.1 (K), D41.1 (K), D42.1 (K), J2.3; also elsewhere on the board
row3: D43.1 (K), D44.1 (K), D45.1 (K), D46.1 (K), D47.1 (K), D48.1 (K), D49.1 (K), D50.1 (K), D51.1 (K), D52.1 (K), D53.1 (K), D54.1 (K), D55.1 (K), D56.1 (K), J2.2; also elsewhere on the board
row4: D57.1 (K), D58.1 (K), D59.1 (K), D60.1 (K), D61.1 (K), D62.1 (K), D63.1 (K), D64.1 (K), D65.1 (K), J2.1; also elsewhere on the board

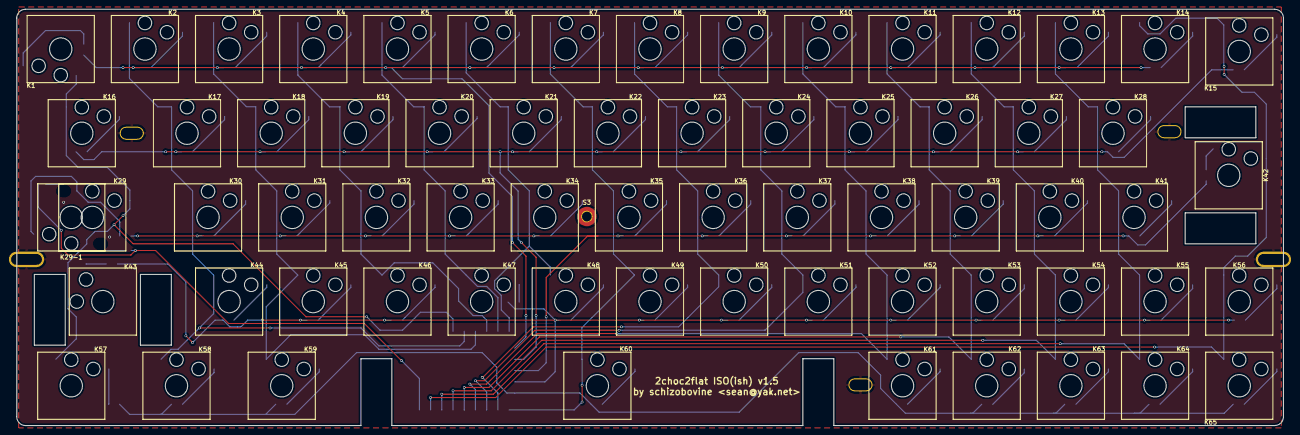
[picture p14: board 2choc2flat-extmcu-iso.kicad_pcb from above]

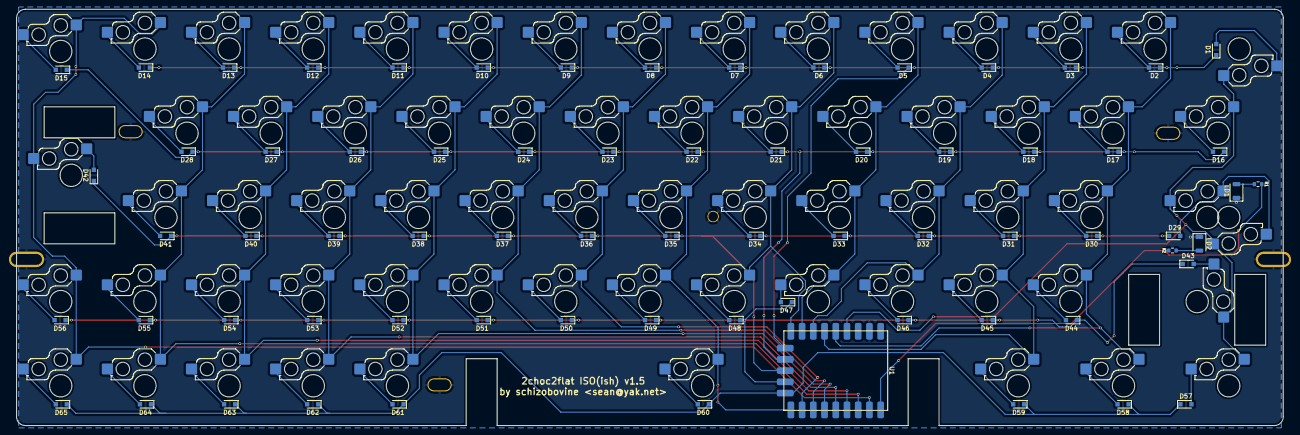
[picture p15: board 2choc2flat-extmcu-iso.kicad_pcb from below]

Board: 2 copper layers, 286.7 x 94.2 mm, 142 parts (70 on the bottom side), 88 nets.

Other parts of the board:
U1: WS-RP2040-Tiny; WAVESHARE_RP2040_TINY

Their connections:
GND: U1.22 (GND); also elsewhere on the board
col0: U1.20 (GPIO29); also elsewhere on the board
col1: U1.19 (GPIO28); also elsewhere on the board
col2: U1.18 (GPIO27); also elsewhere on the board
col3: U1.17 (GPIO26); also elsewhere on the board
col4: U1.16 (GPIO15); also elsewhere on the board
col5: U1.15 (GPIO14); also elsewhere on the board
col6: U1.9 (GPIO8); also elsewhere on the board
col7: U1.8 (GPIO7); also elsewhere on the board
col8: U1.7 (GPIO6); also elsewhere on the board
col9: U1.6 (GPIO5); also elsewhere on the board
col10: U1.5 (GPIO4); also elsewhere on the board
col11: U1.4 (GPIO3); also elsewhere on the board
col12: U1.3 (GPIO2); also elsewhere on the board
col13: U1.2 (GPIO1); also elsewhere on the board
col14: U1.1 (GPIO0); also elsewhere on the board
row0: U1.14 (GPIO13); also elsewhere on the board
row1: U1.13 (GPIO12); also elsewhere on the board
row2: U1.12 (GPIO11); also elsewhere on the board
row3: U1.11 (GPIO10); also elsewhere on the board
row4: U1.10 (GPIO9); also elsewhere on the board

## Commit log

2024-08-23 rename files for external mcu version
    [2choc2flat-extmcu.kicad_pcb, 2choc2flat-extmcu.kicad_sch]
2024-08-24 lshift stab support
    [2choc2flat-extmcu.kicad_sch]
2024-08-24 pure ISO-ish version
    [2choc2flat-extmcu-iso.kicad_sch]
2024-08-25 small board to test 2U stabilizer
    [choc2-gateron-lp-tester.kicad_pcb, choc2-gateron-lp-tester.kicad_sch]
2024-08-25 resize to save costs
    [choc2-gateron-lp-tester.kicad_pcb]
2024-08-26 ansi version
    [2choc2flat-extmcu-ansi.kicad_sch]
2024-08-30 make ISO 64 2u left shift layout
    [2choc2flat-extmcu-iso.kicad_sch]
2024-08-30 fix stab orientation to plate
    [2choc2flat-extmcu-ansi.kicad_sch]
2024-08-30 rejigger stabs to work with plates
    [2choc2flat-extmcu-iso.kicad_sch]
2024-09-06 update readme to reflect current project
2024-09-08 wip attempting rerouting
    [2choc2flat-extmcu-ansi.kicad_sch]
2024-09-08 routing complete
    [2choc2flat-extmcu-ansi.kicad_pcb, 2choc2flat-extmcu-ansi.kicad_sch]
2024-09-09 relayout using MCU with FFC USB
    [2choc2flat-extmcu-iso.kicad_sch]
2024-09-09 wip renaming stuff
    [2choc2flat-extmcu-iso.kicad_pcb, 2choc2flat-extmcu-iso.kicad_sch]
2024-09-09 rerouted, capslock light
    [2choc2flat-extmcu-iso.kicad_pcb, 2choc2flat-extmcu-iso.kicad_sch]
2024-09-15 rev 1.3 layouts
    [2choc2flat-extmcu-ansi.kicad_sch, 2choc2flat-extmcu-iso.kicad_pcb, 2choc2flat-extmcu-iso.kicad_sch]
2024-09-15 remove gerbers output file
2024-09-16 add second caps led, minor tweaks
    [2choc2flat-extmcu-ansi.kicad_sch, 2choc2flat-extmcu-iso.kicad_pcb, 2choc2flat-extmcu-iso.kicad_sch]
2024-09-17 remove old files, update readme
    [2choc2flat-extmcu.kicad_sch]
2024-09-19 whoops wip
    [2choc2flat-extmcu-iso.kicad_pcb, 2choc2flat-extmcu-iso.kicad_sch]
2024-09-19 version 1.4 with foam layers on eco1 and eco2
    [2choc2flat-extmcu-iso-User_Eco1.dxf, 2choc2flat-extmcu-iso-User_Eco2.dxf, 2choc2flat-extmcu-iso.kicad_pcb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]
2024-09-19 wip v1.4 ansi
    [2choc2flat-extmcu-ansi.kicad_sch]
2024-09-19 revision 1.5 bothering to use the castellated pads
    [2choc2flat-extmcu-iso-User_Eco1.dxf, 2choc2flat-extmcu-iso-User_Eco2.dxf, 2choc2flat-extmcu-iso.kicad_pcb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]
2024-09-24 v1.5 ANSI with SMD rp2040 tiny
    [2choc2flat-extmcu-ansi.kicad_sch]
2024-09-26 wip adding RGB lighting
    [2choc2flat-extmcu-ansi.kicad_sch, 2choc2flat-extmcu-iso.kicad_sch]
2024-09-26 add plotted schematics for ref and update readme
2024-09-28 wip adding lighting
    [2choc2flat-extmcu-iso.kicad_sch]
2024-09-30 version 2.0 with RGB backlighting and underglow
    [2choc2flat-extmcu-iso.kicad_sch]
2024-10-01 add schematics for 2.0 version
2024-10-01 rename foam files to include version
    [2choc2flat-extmcu-iso-User_Eco1_v1.5.dxf, 2choc2flat-extmcu-iso-User_Eco2_v1.5.dxf]
2024-10-01 v2.1 few LEDs out of alignment
    [2choc2flat-extmcu-iso.kicad_sch]
2024-10-01 foam for v2.1 build
    [2choc2flat-extmcu-iso-User_Eco1_v2.1.dxf, 2choc2flat-extmcu-iso-User_Eco2_v2.1.dxf]
2024-10-01 remove tester board
    [choc2-gateron-lp-tester.kicad_pcb, choc2-gateron-lp-tester.kicad_sch]
2024-10-02 split out RGB versions into own dirs in prep to restore non-RGB versions
    [2choc2flat-extmcu-ansi-rgb.kicad_sch, 2choc2flat-extmcu-iso-User_Eco1_v1.5.dxf, 2choc2flat-extmcu-iso-User_Eco1_v2.1.dxf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]
2024-10-02 add files for ISOish plate
    [s64-2u-lshift-iso-plate-2.dxf]
2024-10-02 restore non-RGB versions from history into separate dirs
    [2choc2flat-extmcu-ansi.kicad_sch, 2choc2flat-extmcu-iso-User_Eco1.dxf, 2choc2flat-extmcu-iso-User_Eco2.dxf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]
2024-10-02 symlink to plate dir since they're the same across the two version
2024-10-02 ISOish solderable version with the 3rd pin anchor
    [2choc2flat-extmcu-ansi-rgb.kicad_sch, 2choc2flat-extmcu-iso-User_Eco1.dxf, 2choc2flat-extmcu-iso-User_Eco1_v1.5.dxf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]
2024-10-10 redo underglow because i failed to map the pads correctly
    [2choc2flat-extmcu-iso-rgb.kicad_sch]
2024-10-10 solderable version
    [2choc2flat-extmcu-iso-solder.kicad_pcb, 2choc2flat-extmcu-iso-solder.kicad_sch]
2024-10-10 ignore kicad lockfiles
2024-10-16 fixing more fuckups
    [2choc2flat-extmcu-iso-rgb.kicad_sch, 2choc2flat-extmcu-iso-solder.kicad_pcb]
2024-10-22 yet another revision to fix footprints
2024-11-04 update solder foam and RGB schematic
    [2choc2flat-extmcu-iso-User_Eco1_v2.3.dxf, 2choc2flat-extmcu-iso-User_Eco2_v2.3.dxf]
2024-11-04 update ANSI for foam
    [2choc2flat-extmcu-ansi.kicad_sch]
2024-11-04 no longer going to do this one
    [2choc2flat-extmcu-ansi-rgb.kicad_sch]
